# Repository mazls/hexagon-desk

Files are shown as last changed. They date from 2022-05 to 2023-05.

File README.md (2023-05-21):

<h1 align="center"> Hexagon Desk </h1>
<h3 align="center"> Epoxy Coffe Table </h3>

This work is licensed under a
[Creative Commons Attribution-NonCommercial-ShareAlike 4.0 International License][cc-by-nc-sa].

[][cc-by-nc-sa]

[cc-by-nc-sa]: http://creativecommons.org/licenses/by-nc-sa/4.0/
[cc-by-nc-sa-image]: https://licensebuttons.net/l/by-nc-sa/4.0/88x31.png
[cc-by-nc-sa-shield]: https://img.shields.io/badge/License-CC%20BY--NC--SA%204.0-lightgrey.svg
<p align="center"> 
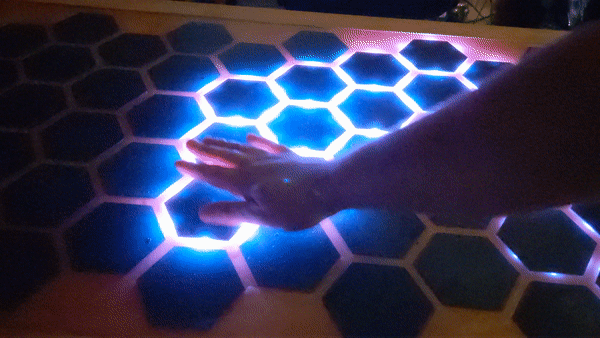
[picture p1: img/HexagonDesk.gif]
Hexagon Desk
  
</p>

<!-- TABLE OF CONTENTS -->
<h2 id="table-of-contents"> :book: Table of Contents</h2>

<details open="open">
  <summary>Table of Contents</summary>
  <ol>
    <li><a href="#about-the-project"> ➤ About The Project</a></li>
    <li><a href="#overview"> ➤ Overview</a></li>
    <li><a href="#project-files-description"> ➤ Project Files Description</a></li>
    <li><a href="#getting-started"> ➤ Getting Started</a></li>
    <li><a href="#PCB"> ➤ PCB: Main-PCB </a></li>
	<li><a href="#HexagonPCB"> ➤ PCB: HexagonPCB </a></li>
	<li><a href="#Links"> ➤ Useful Links: </a></li>
	<li><a href="#Sponsor"> ➤ Sponsor: </a></li>
  </ol>
</details>



<!-- ABOUT THE PROJECT -->
<h2 id="about-the-project"> :pencil: About The Project</h2>

<p align="justify"> 
  I saw a short TikTok with a led table that lights up when touched and immediately felt like building it myself. So i designed my own Main-PCB and little hexagonal PCBs for the light and touch. Unfortunately, there were a few setbacks due to the availability of some components. So I had to equip the main PCB with self soldered components. I also had to get the touch sensors externally and solder them on. If the whole thing with the chips calms down a bit I will tackle the whole thing again and simplify it.
</p>
<p align="center"> 
  HexagonDesk
</p>



<!-- OVERVIEW -->
<h2 id="overview"> :cloud: Overview</h2>

<p align="justify"> 
  This project still requires a lot of manual work. The main board still has to be assembled by yourself, as well as the touch sensors on the Hexagon boards.
Also a lot of wiring has to be done. The touch sensors are individually connected to the main board. The WS2812B on the hexagons are looped through per channel.

I have created a bom and instructions. however, these are still far from good. I am always working on improving these and also on the programme/boards.
I have opened the discussions area for questions, suggestions etc.
</p>
<p align="center"> 
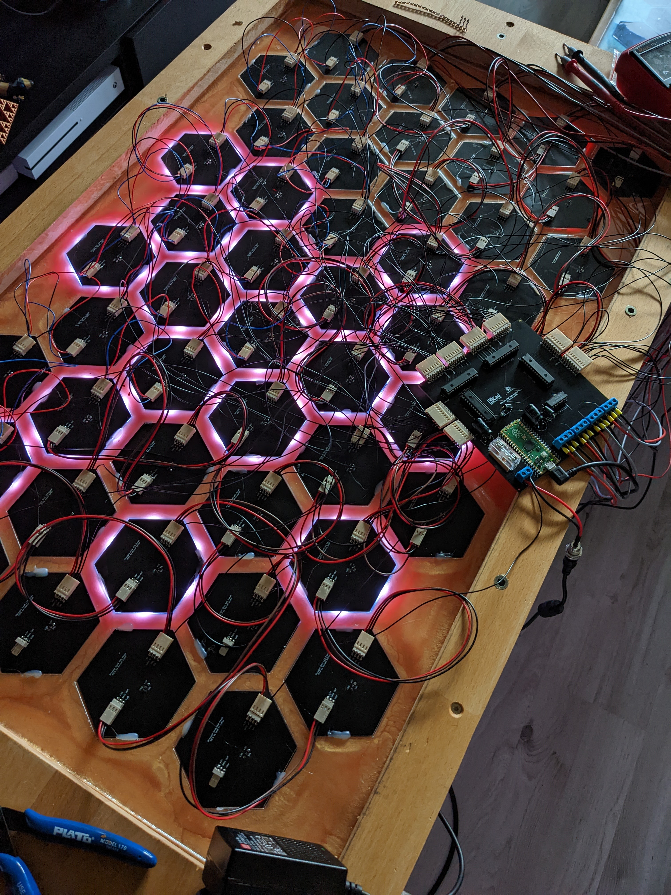
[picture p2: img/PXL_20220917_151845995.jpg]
HexagonWiring
  
</p>



<!-- PROJECT FILES DESCRIPTION -->
<h2 id="project-files-description"> :floppy_disk: Project Files Description</h2>

<ul>
  <li><b>Desk_PRG.ino</b> - Is the first version with an ESP32 as main controller</li>
  <li><b>Desk_PRG_RP2040.ino</b> - Is the current version with a RP2040 as controller.</li>
  <li><b>Adafruit_MCP23017.cpp/Adafruit_MCP23017.h</b> - Is for the MCP23017 I2C communication</li>
  <li><b>FastLED</b> - This is a modified Version of FastLED V3.4 to work with the RP2040</li>
</ul>



<!-- GETTING STARTED -->
<h2 id="getting-started"> :book: Getting Started</h2>
<p>Install the RP2040 Board: https://github.com/earlephilhower/arduino-pico </p>
<p>For ESP32 you have to install ESP32 Boards: https://randomnerdtutorials.com/installing-the-esp32-board-in-arduino-ide-windows-instructions/ </p>

<p>For RP2040 You have to clone the repo and copy the FastLED folder in your "...\Dokuments\Arduino\libraries\" folder to work with the RP2040</p>

<p>Now you should be able to compile the</p>
<pre><code>Desk_PRG_RP2040.ino</code></pre>

<p>In the header you should config your Setup</p>
<p>Just configure the amount of Hexagon PCBs you have connectet to channel 0-3</p>
<pre><code>#define Hexagons_channel_0  12</code></pre>
<pre><code>#define Hexagons_channel_1  12</code></pre>
<pre><code>#define Hexagons_channel_2  12</code></pre>
<pre><code>#define Hexagons_channel_3  14</code></pre>
<p>In this config i have connectet 12 Hexagon PCBs to channel 0, 12 Hexagon PCBs to channel 1, 12 Hexagon PCBs to channel 2 and 14 Hexagon PCBs to channel 3. The desk was build with 50 Hexagon PCBs. The maximum is 64, but this can be expanded with more MCP23017.
</p>



<!-- Main-PCB -->
<h2 id="Main-PCB"> :small_orange_diamond: Main-PCB: What is the Main-PCB</h2>

<p> The Main-PCB contains 4x MCP23017, 2x 1500uF Capacitor, 1x Fuse holder, 1x SN74HC125N and one ESP32 Dev Kit C / Raspberry Pi Pico</p>
<p>The MCP23017 are communicating over I2C, every MCP23017 has 16 Inputs/Outputs.</p>
<p>The SN74HC125N is to shift the data channel from 3.3V to 5V so the leds don't glitch.</p>



<!-- HexagonPCB -->
<h2 id="HexagonPCB"> :small_orange_diamond: HexagonPCB: The LED and Touch PCBs</h2>

<p>I have designed this PCB to integrate the LEDs and the Touch Sensor.</p>
<p>The PCB has a "Data IN" and "Data OUT" so it is possible to connect multiple PCBs to act as a WS2812B Strip</p>
<p>Every PCB has a "Signal" Pin which connects the signal output from the TTP223 PCB to the Main-PCB</p>
<p>The Input Voltage is 5V for the PCB</p>
<p>I have scraped some varnish from the touch surface of the TTP223 sensors and soldered a cable there, which then functions as a touch sensor.</p>

<p align="center"> 
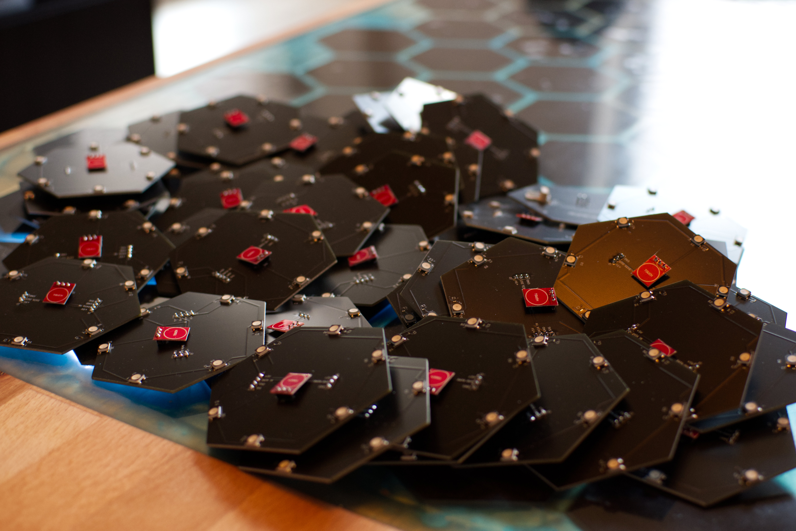
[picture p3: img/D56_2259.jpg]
HexagonPCB
  
</p>



<!-- Links -->
<h2 id="Links"> :scroll: Some useful Links: </h2>

<p>BOM</p>
[Tisch_BOM.xlsx](https://github.com/mazls/hexagon-desk/blob/main/BOM/Tisch_BOM.xlsx)
</p>

<p>Schematic Wiring</p>
[Wiring.pdf](https://github.com/mazls/hexagon-desk/files/8800328/Wiring.pdf)
</p>
<p>Desk Cutout for 50 Hexagons</p>
[Hex_Desk_Ausschnitt.pdf](https://github.com/mazls/hexagon-desk/blob/main/Woodwork/Hex_Desk_Ausschnitt.pdf)
</p>
<p>Desk Legs</p>
[Table_legs.pdf](https://github.com/mazls/hexagon-desk/blob/main/Woodwork/Table_legs.pdf)
</p>

<p>Print files can be found here:</p>
https://www.printables.com/model/200964-hexagon-led-coffee-table
<p align="center"> 
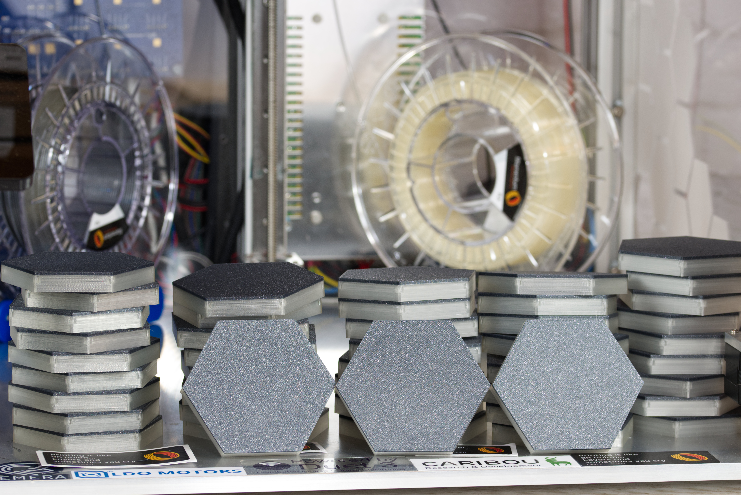
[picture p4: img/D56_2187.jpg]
HexagonPrint
  
</p>

</p>
<p>Dev Kit link:</p>
https://www.az-delivery.de/en/products/esp32-developmentboard
</p>
<p>Videos</p>
https://youtu.be/I4rWym8PK4s

https://www.youtube.com/watch?v=-OrUfqWGYhM&feature=emb_title



<!-- Sponsor -->
<h2 id="Sponsor"> ➤ Sponsor: </h2>
PCBway kindly sponsored a batch of PCBs which you can see pictures of inside the _img folder.
The pcbs came in an absolutely outstanding quality and also very fast!
<p>Ordering at PCBWay is simple:</p>
Upload the files from the desired folder
After submitting your file, a PCBWay engineer will spend a few minutes reviewing your file to make sure everything goes smoothly for production. For high-priority work, it's always good to see how things are progressing. You have the opportunity to check the production status of each step. For assembled PCB, PCBWay will also send you sample photos for preview and confirmation.

<p align="center"> 
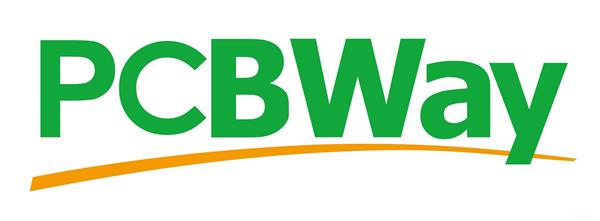
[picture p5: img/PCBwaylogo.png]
  
</p>

http://pcbway.com

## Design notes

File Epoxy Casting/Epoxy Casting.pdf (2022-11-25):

Epoxy Casting:

1. Pour in one layer about 2mm thick with clear epoxy
2. Let it harden (one day)
3. Pour in a second layer about 1-2mm but also brush the hexagons with epoxy and place them inside the table
4. Let all harden
5. Pour the color layer to max hexagon height

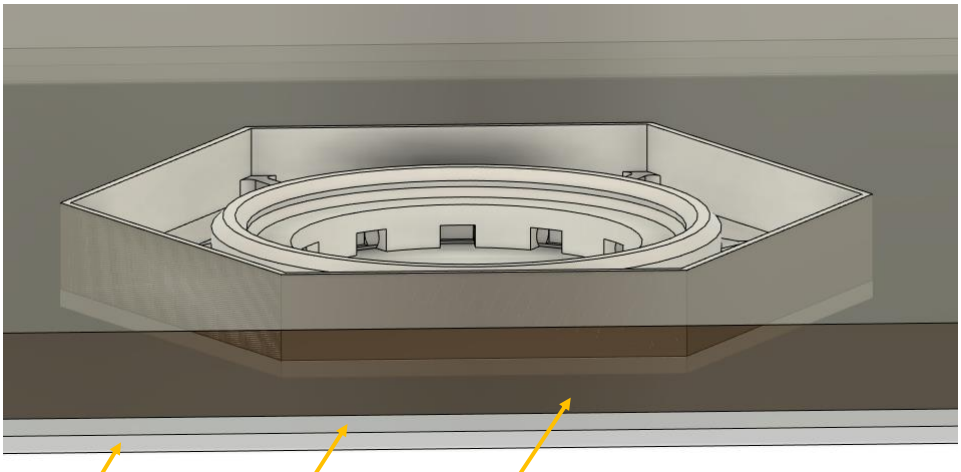
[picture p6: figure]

1. Clear Layer | 2. Clear Layer with Hexagons

3.Color Layer

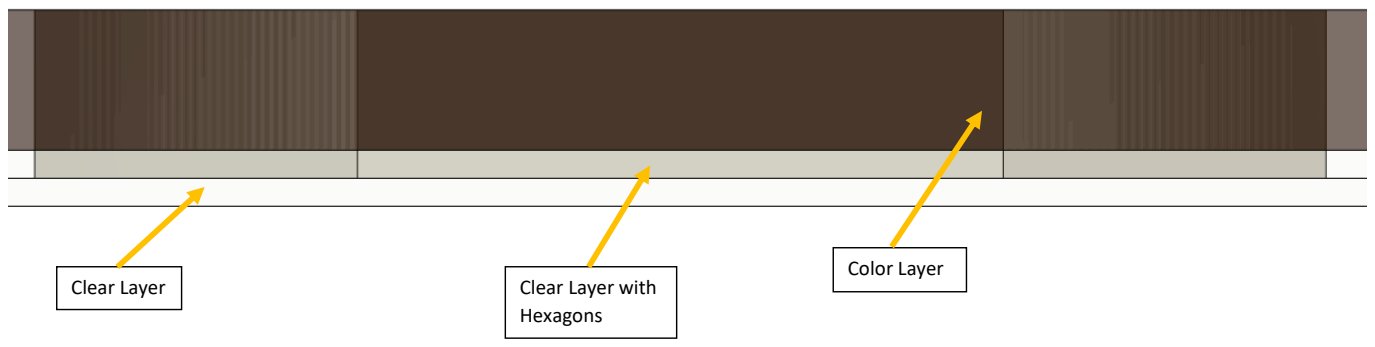
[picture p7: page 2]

Color Layer
Clear Layer with
Hexagons

Clear Layer

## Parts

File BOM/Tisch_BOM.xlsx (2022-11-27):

Name | Anzahl | Preis | Gesamt | Bild | Link
Hexagon PCB | 50 | 4.20 € | 210.00 € |  | PCBWay
Main PCB | 1 | 6.97 € | 6.97 € |  | PCBWay
2 Pol Schraubklemme | 1 | 0.40 € | 0.40 € |  | CTB0102-2: Lötbare Schraubklemme - 2-pol, RM 5 mm, 90° bei reichelt elektronik (https://www.reichelt.de/loetbare-schraubklemme-2-pol-rm-5-mm-90--ctb0102-2-p292680.html?trstct=pos_1&nbc=1)
3 Pol Schraubklemme | 4 | 0.40 € | 1.60 € |  | CTB0102-3: Lötbare Schraubklemme - 3-pol, RM 5 mm, 90° bei reichelt elektronik (https://www.reichelt.de/loetbare-schraubklemme-3-pol-rm-5-mm-90--ctb0102-3-p292681.html?trstct=vrt_pdn&nbc=1)
Sicherungshalter | 1 | 0.20 € | 0.20 € |  | HALJIA 10 x Leiterplatten-Sicherungshalter mit Abdeckung für Sicherungen mit 5 x 20 mm, 250 V, 6 A: Amazon.de: Baumarkt (https://www.amazon.de/gp/product/B07BFMXHN8/ref=ppx_yo_dt_b_search_asin_title?ie=UTF8&psc=1)
Sicherung | 1 | 0.20 € | 0.20 € |  | BOJACK 15 Values 150pcs Schnellschlag Glassicherungen Sortiment Set 5x20mm Sicherung 250V Sicherungen 0,1 0,2 0,25 0,5 1 1,5 2 3 4 5 8 10 12 15 20A Verpackung in einer durchsichtigen Kunststoffbox : Amazon.de: Baumarkt (https://www.amazon.de/gp/product/B07TF68QZC/ref=ppx_yo_dt_b_search_asin_title?ie=UTF8&psc=1)
Kondensator 1500uF | 1 | 1.40 € | 1.40 € |  | Aerzetix: 5x LOW ESR Kondensator chemischen 1500μF ± 20% 16V THT 105 ° C 5000h Radial Ø12.5x20mm 0.05Ω 1400mA C14706: Amazon.de: Gewerbe, Industrie & Wissenschaft (https://www.amazon.de/Aerzetix-Kondensator-chemischen-1500%CE%BCF-%C3%9812-5x20mm/dp/B01N15CYYA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)
Leimholzplatte (Buche, Qualität: A/B, 1.000x600 x 18 mm) | 3 | 34.50 € | 103.50 € |  | Exclusivholz Leimholzplatte (Buche, Qualität: A/B, 1.000 x 600 x 18 mm) | BAUHAUS (https://www.bauhaus.info/leimholzplatten/exclusivholz-leimholzplatte/p/14035174)
MCP23017 | 4 | 1.85 € | 7.40 € |  | MCP 23017-E - SP: I - O-Erweiterung, 16bit, 1,8 - 5V, Seriell, I2C, DIP-28 bei reichelt elektronik (https://www.reichelt.de/i-o-erweiterung-16bit-1-8-5v-seriell-i2c-dip-28-mcp-23017-e-sp-p140074.html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)
SN74HC125N | 1 | 0.34 € | 0.34 € |  | 74HC 125: BUS Puffer, 3-State, 2 ... 6 V, DIL-14 bei reichelt elektronik (https://www.reichelt.de/bus-puffer-3-state-2--6-v-dil-14-74hc-125-p3132.html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)
DC Hohlstecker 5.5x2.1mm | 1 | 1.30 € | 1.30 € |  | RUNCCI-YUN DC Mount Adapter Set, 6X DC Hohlstecker（Mit Kabel） 6 X DC Power Jack Socket 5,5 X 2,1 mm DC Stecker Buchse Adapter für Audio/Video/Handy/Überwachungskameras: Amazon.de: Elektronik & Foto (https://www.amazon.de/gp/product/B089DXQDS9/ref=ppx_yo_dt_b_search_asin_title?ie=UTF8&psc=1)
5v Netzteil | 1 | 18.70 € | 18.70 € |  | GS15E-1P1J: Steckernetzteil, 12 W, 5 V, 2,4 A, stabilisiert bei reichelt elektronik (https://www.reichelt.de/steckernetzteil-12-w-5-v-2-4-a-stabilisiert-gs15e-1p1j-p161604.html?trstct=pos_0&nbc=1)
TTP223 Touch sensor | 61 | 0.50 € | 30.50 € |  | TTP223 Touch Schlüssel Schalter Modul Berühren Taste Self Locking/Keine Kapazitiven Schalter Einzel Kanal Wiederaufbau|Integrierte Schaltkreise| - AliExpress (https://de.aliexpress.com/item/33010351631.html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)
Epoxid Harz 4.5kg | 1 | 59.99 € | 59.99 € |  | EpoxyPlast 3D B50 Deep Pour Resin - Ultra Diamond Clear Anti-UV - E... (kandydip.de) (https://kandydip.de/ecom/prestashop/epoxidharz-dipon/3993-epoxyplast-3d-b50-deep-pour-resin-ultra-diamond-clear-anti-uv-epoxidharz-i-epoxy-resin-diponr.html)
Formtrennband | 1 | 6.05 € | 6.05 € |  | Formentrennband für Epoxidharze - Trennmittel I Release Agents (kandydip.de) (https://kandydip.de/ecom/prestashop/trennmittel-i-release-agents/4010-formentrennband-fur-epoxidharze-trennmittel-i-release-agents-diponr-4063636027441.html)
Metallic Pulver | 1 | 8.99 € | 8.99 € |  | Red Firestorm Colorshift Pearl Pigment - ColorShifts (kandydip.de) (https://kandydip.de/ecom/prestashop/dipon-colorshift-pearls/1590-red-firestorm-colorshift-pearl-pigment-colorshifts-diponr-4063636005364.html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)
Holzeinsätze M6 - 10mm | 20 | 0.30 € | 6.00 € |  | FTVOGUE 20 stücke Innensechskant Antriebskopfschraube Kohlenstoffstahl Insert Muttern Gewinde für Holz Möbel (M6*10mm) : Amazon.de: Baumarkt (https://www.amazon.de/gp/product/B07PYP344Y/ref=ppx_yo_dt_b_search_asin_title?ie=UTF8&psc=1)
M6x 16 Schrauben | 50 | 0.17 € | 8.35 € |  | M6 ISO 7380-2 A2 V2A Edelstahl Linsenkopfschrauben Innensechskant Flansch M6x | eBay (https://www.ebay.de/itm/162277039480)
PETG Schwarz | 1 | 29.99 € | 29.99 €
PETG Transparent | 1 | 29.99 € | 29.99 €
Hartöl | 1 | 19.95 € | 19.95 € |  | CLOU Hartöl: Zur Renovierung und Pflege von stark beanspruchtem Massivholz, z.B. Treppen, Möbel und Parkett, farblos, 0,75 L : Amazon.de: Baumarkt (https://www.amazon.de/CLOU-304843-Clou-Hart%C3%B6l-farblos/dp/B004GTYPFC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)
IC Buchsen Set | 1 | 8.99 € | 8.99 € |  | DollaTek 66-teilige Dip-IC-Buchsen Adapter Lötbuchsen-Kit 6/8/14/16/18/20/24/28 Stifte : Amazon.de: Gewerbe, Industrie & Wissenschaft (https://www.amazon.de/gp/product/B08HQW9PS8/ref=ppx_yo_dt_b_search_asin_title?ie=UTF8&psc=1)
Kupplungs-Leergehäuse, Crimptechnik, 3-polig | 100 | 0.02 € | 2.00 € |  | PSK 254 - 3W: Kupplungs-Leergehäuse, Crimptechnik, 3-polig bei reichelt elektronik (https://www.reichelt.de/kupplungs-leergehaeuse-crimptechnik-3-polig-psk-254-3w-p14858.html?trstct=pos_0&nbc=1)
PSK 254/4W Kupplungs-Leergehäuse, Crimptechnik, 4-polig | 100 | 0.02 € | 2.00 € |  | PSK 254 - 4W: Kupplungs-Leergehäuse, Crimptechnik, 4-polig bei reichelt elektronik (https://www.reichelt.de/kupplungs-leergehaeuse-crimptechnik-4-polig-psk-254-4w-p694.html?trstct=pos_0&nbc=1)
PSK 254/8W Kupplungs-Leergehäuse, Crimptechnik, 8-polig | 4 | 0.04 € | 0.16 € |  | PSK 254 - 8W: Kupplungs-Leergehäuse, Crimptechnik, 8-polig bei reichelt elektronik (https://www.reichelt.de/kupplungs-leergehaeuse-crimptechnik-8-polig-psk-254-8w-p14860.html?trstct=pos_0&nbc=1)
CRIMPZANGE PSK | 1 | 20.30 € | 20.30 € |  | CRIMPZANGE PSK: Crimpzange, PSK-Kontakte bei reichelt elektronik (https://www.reichelt.de/crimpzange-psk-kontakte-crimpzange-psk-p6844.html?&trstct=pos_1&nbc=1)
PSK-KONTAKTE 20x | 50 | 0.24 € | 12.00 € |  | PSK-KONTAKTE: Crimpkontakte für psk 254 - ..., 20 Stück bei reichelt elektronik (https://www.reichelt.de/crimpkontakte-fuer-psk-254--20-stueck-psk-kontakte-p14861.html?trstct=pos_0&nbc=1)
PSS 254/3W Printstecker | 100 | 0.09 € | 9.00 € |  | PSS 254 - 3W: Printstecker, Einzelstecker, gewinkelt, 3-polig bei reichelt elektronik (https://www.reichelt.de/printstecker-einzelstecker-gewinkelt-3-polig-pss-254-3w-p14910.html?trstct=pos_0&nbc=1)
PSS 254/4W | 100 | 0.13 € | 13.00 € |  | PSS 254 - 4W: Printstecker, Einzelstecker, gewinkelt, 4-polig bei reichelt elektronik (https://www.reichelt.de/printstecker-einzelstecker-gewinkelt-4-polig-pss-254-4w-p137974.html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)
PSS 254/8W | 4 | 0.11 € | 0.44 € |  | PSS 254 - 8W: Printstecker, Einzelstecker, gewinkelt, 8-polig bei reichelt elektronik (https://www.reichelt.de/printstecker-einzelstecker-gewinkelt-8-polig-pss-254-8w-p14914.html?trstct=pos_0&nbc=1)
Pi Pico, RP2040 | 1 | 4.00 € | 4.00 € |  | RASP PI PICO: Raspberry Pi Pico, RP2040, Cortex-M0+, microUSB bei reichelt elektronik (https://www.reichelt.de/raspberry-pi-pico-rp2040-cortex-m0-microusb-rasp-pi-pico-p295706.html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)
LITZE BL | 5 | 0.95 € | 4.75 € |  | LITZE BL: Kupferlitze isoliert, 10 m, 1 x 0,14 mm², blau bei reichelt elektronik (https://www.reichelt.de/kupferlitze-isoliert-10-m-1-x-0-14-mm-blau-litze-bl-p10292.html?trstct=pos_0&nbc=1)
LITZE SW | 5 | 0.95 € | 4.75 € |  | LITZE SW: Kupferlitze isoliert, 10 m, 1 x 0,14 mm², schwarz bei reichelt elektronik (https://www.reichelt.de/kupferlitze-isoliert-10-m-1-x-0-14-mm-schwarz-litze-sw-p10298.html?search=LITZE+sw)
LITZE RT | 5 | 0.95 € | 4.75 € |  | LITZE RT: Kupferlitze isoliert, 10 m, 1 x 0,14 mm², rot bei reichelt elektronik (https://www.reichelt.de/kupferlitze-isoliert-10-m-1-x-0-14-mm-rot-litze-rt-p10297.html?trstct=pos_0&nbc=1)
 |  |  | 637.96 €

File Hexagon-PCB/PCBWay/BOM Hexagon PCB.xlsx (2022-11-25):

 |  |  | xxxx xxxx xxxxx xxPCS BOM (Sample Bill of Materials)
Item # | *Designator | *Qty | Manufacturer | *Mfg Part # | Description / Value | *Package/Footprint | Type | Your Instructions / Notes
1 | D1, D2, D3, D4, D5, D6 | 6 | Worldsemi | WS2812B-B | RGB 5050(mm) Light Emitting Diodes (LED) ROHS | 5050(mm) | SMD
2 | C1, C2, C3, C4, C5, C6 | 6 | Samsung Electro-Mechanics | CL05B104KO5NNNC | 16V 100nF X7R ±10% 0402 Multilayer Ceramic Capacitors MLCC - SMD/SMT ROHS | 0402 | SMD
Need a quick and accurante quote? Need an efficient production? Please read SMT Ordering Necessary Files & Info in 1 minute. Thank you very much! (https://www.pcbway.com/smt_ordering_guide.html)
Click for Instructions on How to Create a BOM (https://www.pcbway.com/blog/PCB_Assembly/How_to_Build_a_BOM__Bill_Of_Materials_.html)

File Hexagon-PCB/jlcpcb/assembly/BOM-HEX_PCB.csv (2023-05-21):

Comment | Designator | Footprint | LCSC
0.1uF | C1 | C_0201_0603Metric
WS2812B | D3 | LED_WS2812B_PLCC4_5.0x5.0mm_P3.2mm
0.1uF | C4 | C_0201_0603Metric
Conn_01x03_Male | J3 | PinHeader_1x03_P2.54mm_Vertical
WS2812B | D4 | LED_WS2812B_PLCC4_5.0x5.0mm_P3.2mm
0.1uF | C2 | C_0201_0603Metric
Conn_01x04_Male | J1 | PinHeader_1x04_P2.54mm_Vertical
WS2812B | D5 | LED_WS2812B_PLCC4_5.0x5.0mm_P3.2mm
0.1uF | C5 | C_0201_0603Metric
WS2812B | D6 | LED_WS2812B_PLCC4_5.0x5.0mm_P3.2mm
0.1uF | C3 | C_0201_0603Metric
Conn_01x03_Male | J2 | PinHeader_1x03_P2.54mm_Vertical
WS2812B | D1 | LED_WS2812B_PLCC4_5.0x5.0mm_P3.2mm
WS2812B | D2 | LED_WS2812B_PLCC4_5.0x5.0mm_P3.2mm
0.1uF | C6 | C_0201_0603Metric

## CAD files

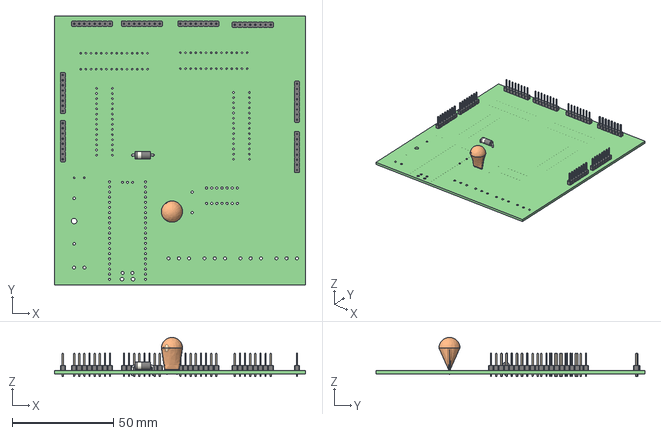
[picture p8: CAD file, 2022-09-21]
Desk_PRG/Desk_PRG_RP2040/Hexagon_Desk_RP2040.step
124.3 x 133.1 x 19.4 mm
Hexagon_Desk_RP2040 PCB

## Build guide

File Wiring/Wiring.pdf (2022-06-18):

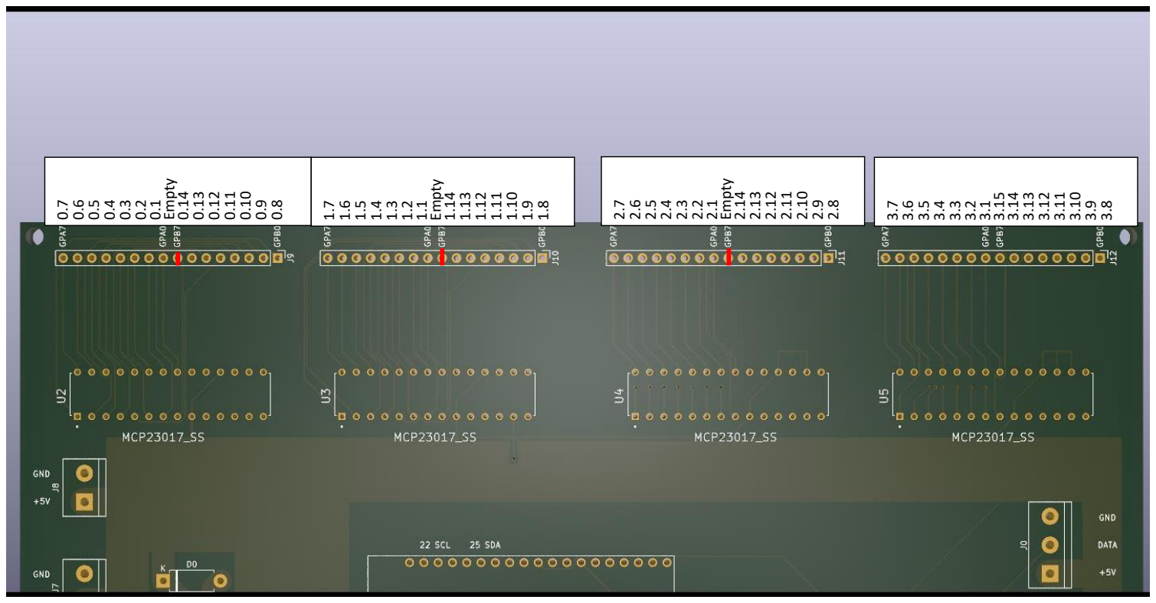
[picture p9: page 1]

0.7

0.6

0.5

0.4

0.3

0.2

0.1

Empty
0.14

0.13

0.12

0.11

0.10
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
Empty
1.14

1.13

1.12

1.11

1.10
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
Empty
2.14

2.13

2.12

2.11

2.10
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
3.15

3.14

3.13

3.12

3.11

3.10
3.9

3.8

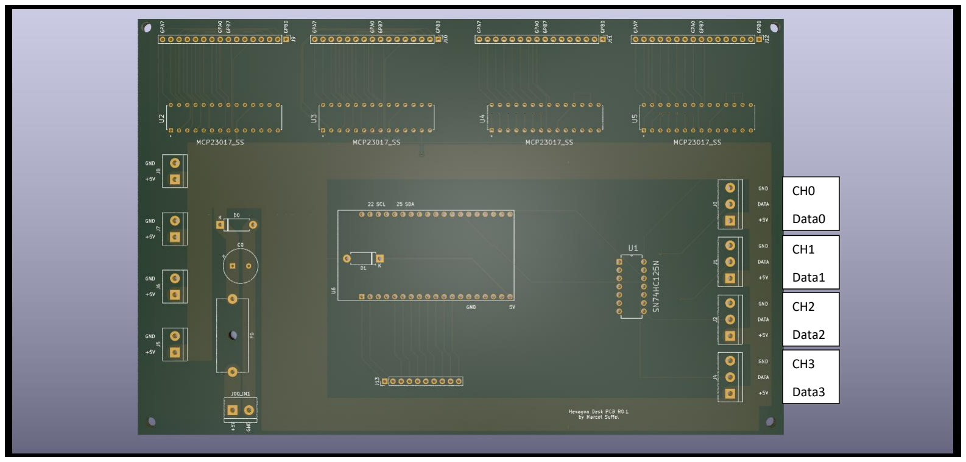
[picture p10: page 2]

CH0

Data0

CH1

Data1

CH2

Data2

CH3

Data3

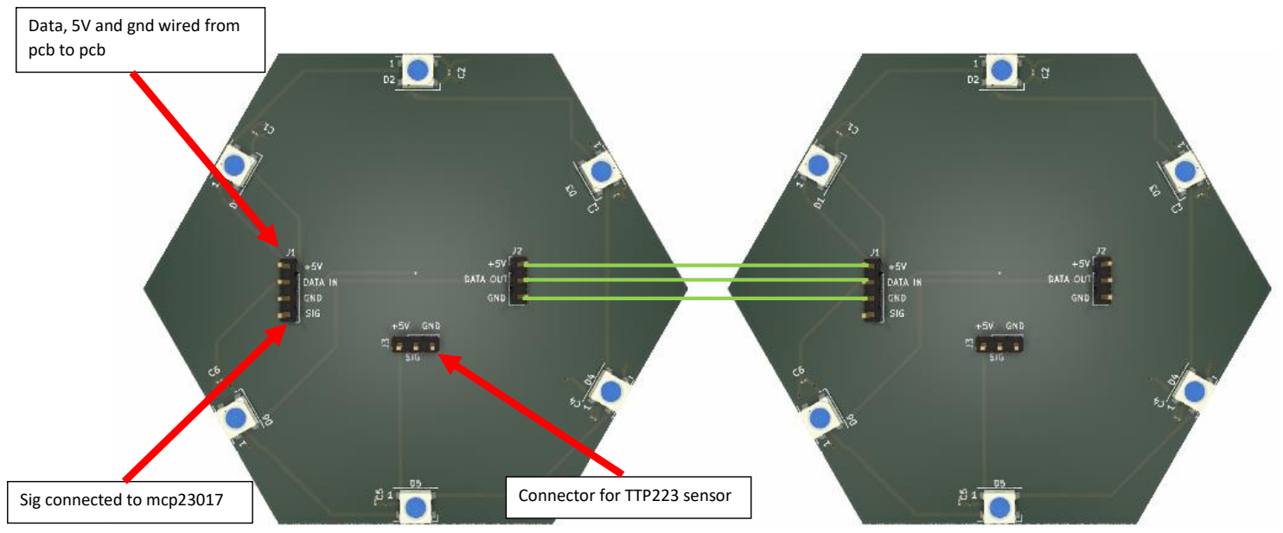
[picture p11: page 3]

Sig connected to mcp23017

Data, 5V and gnd wired from pcb to pcb

Connector for TTP223 sensor

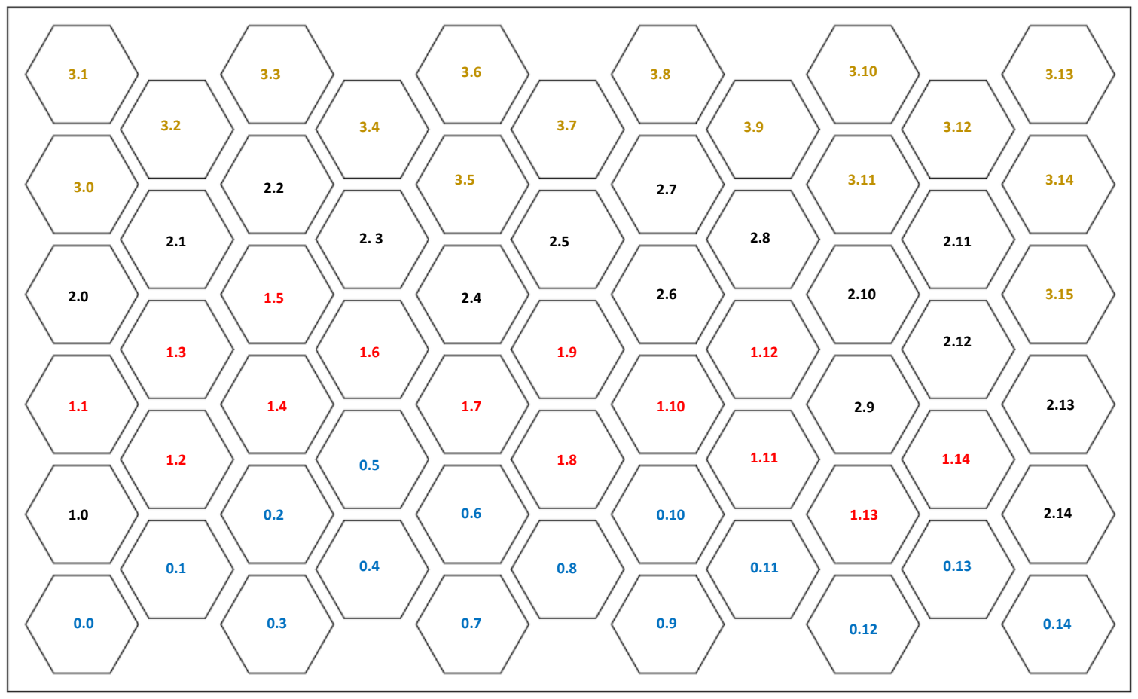
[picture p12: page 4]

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
0.10

0.9
0.12

0.11 0.13

0.14

1.0

1.2

1.1 1.4

1.3 1.6

1.5

1.7

1.8

1.9

1.10

1.11

1.12

1.13

1.14

2.0

2.1

2.2

2. 3

2.4

2.5

2.7

2.6

2.8

2.9

2.10

2.13

2.11

2.12

2.14

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
3.11

3.10

3.12

3.13

3.14

3.15

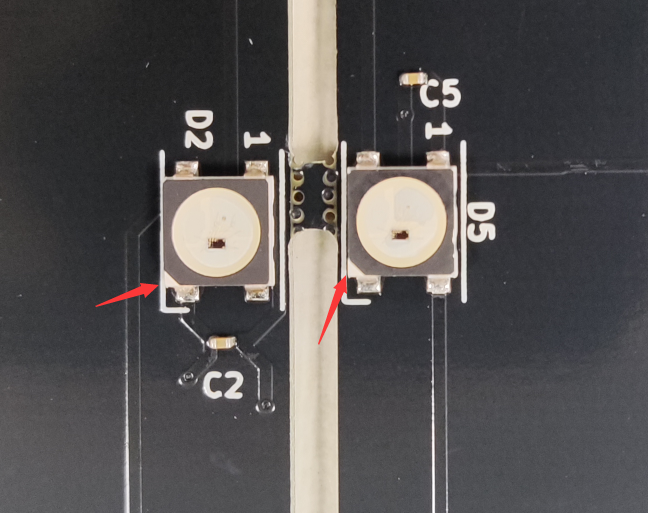
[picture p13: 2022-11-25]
Hexagon-PCB/PCBWay/ReferencePicture for Manufacturing/point to cathode.png

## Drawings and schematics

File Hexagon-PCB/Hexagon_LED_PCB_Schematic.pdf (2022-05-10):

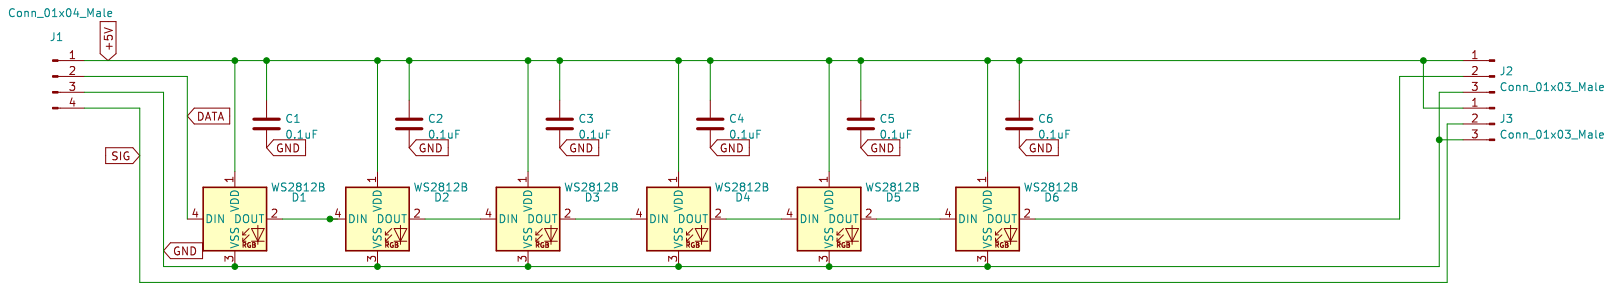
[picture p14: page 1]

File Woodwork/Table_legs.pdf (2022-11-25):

18

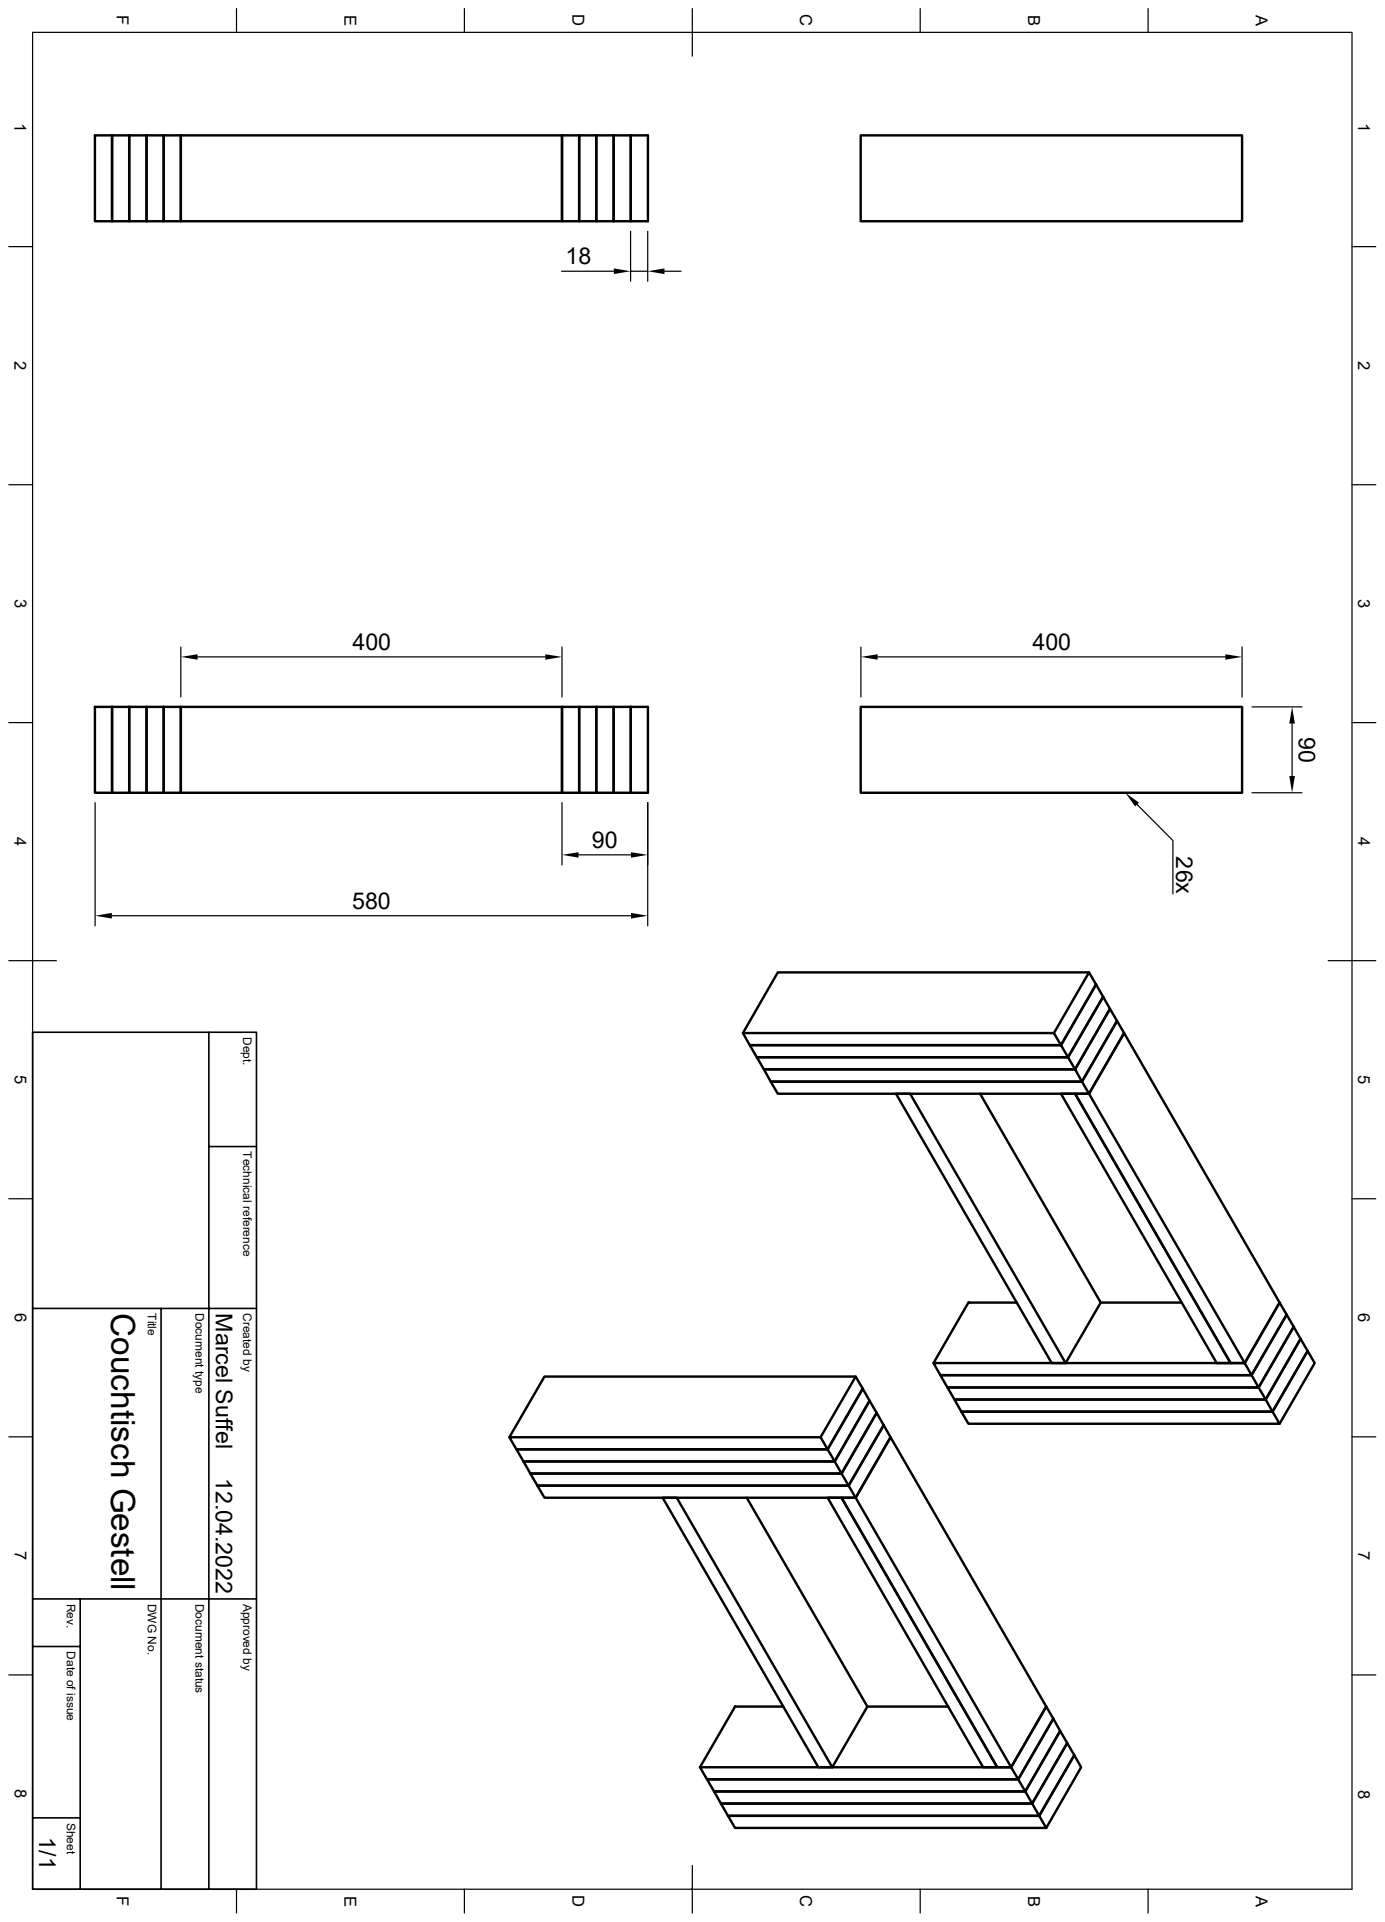
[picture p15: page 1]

1 A 2 3 4 5 6 7 8 1 2 3 4 5 6 7 8 FEDCB FEDCBA Dept. Technical reference Created by Approved by Title DWG No. Document type Document status Rev. Date of issue Sheet 12.04.2022 1/1 Couchtisch Gestell Marcel Suffel

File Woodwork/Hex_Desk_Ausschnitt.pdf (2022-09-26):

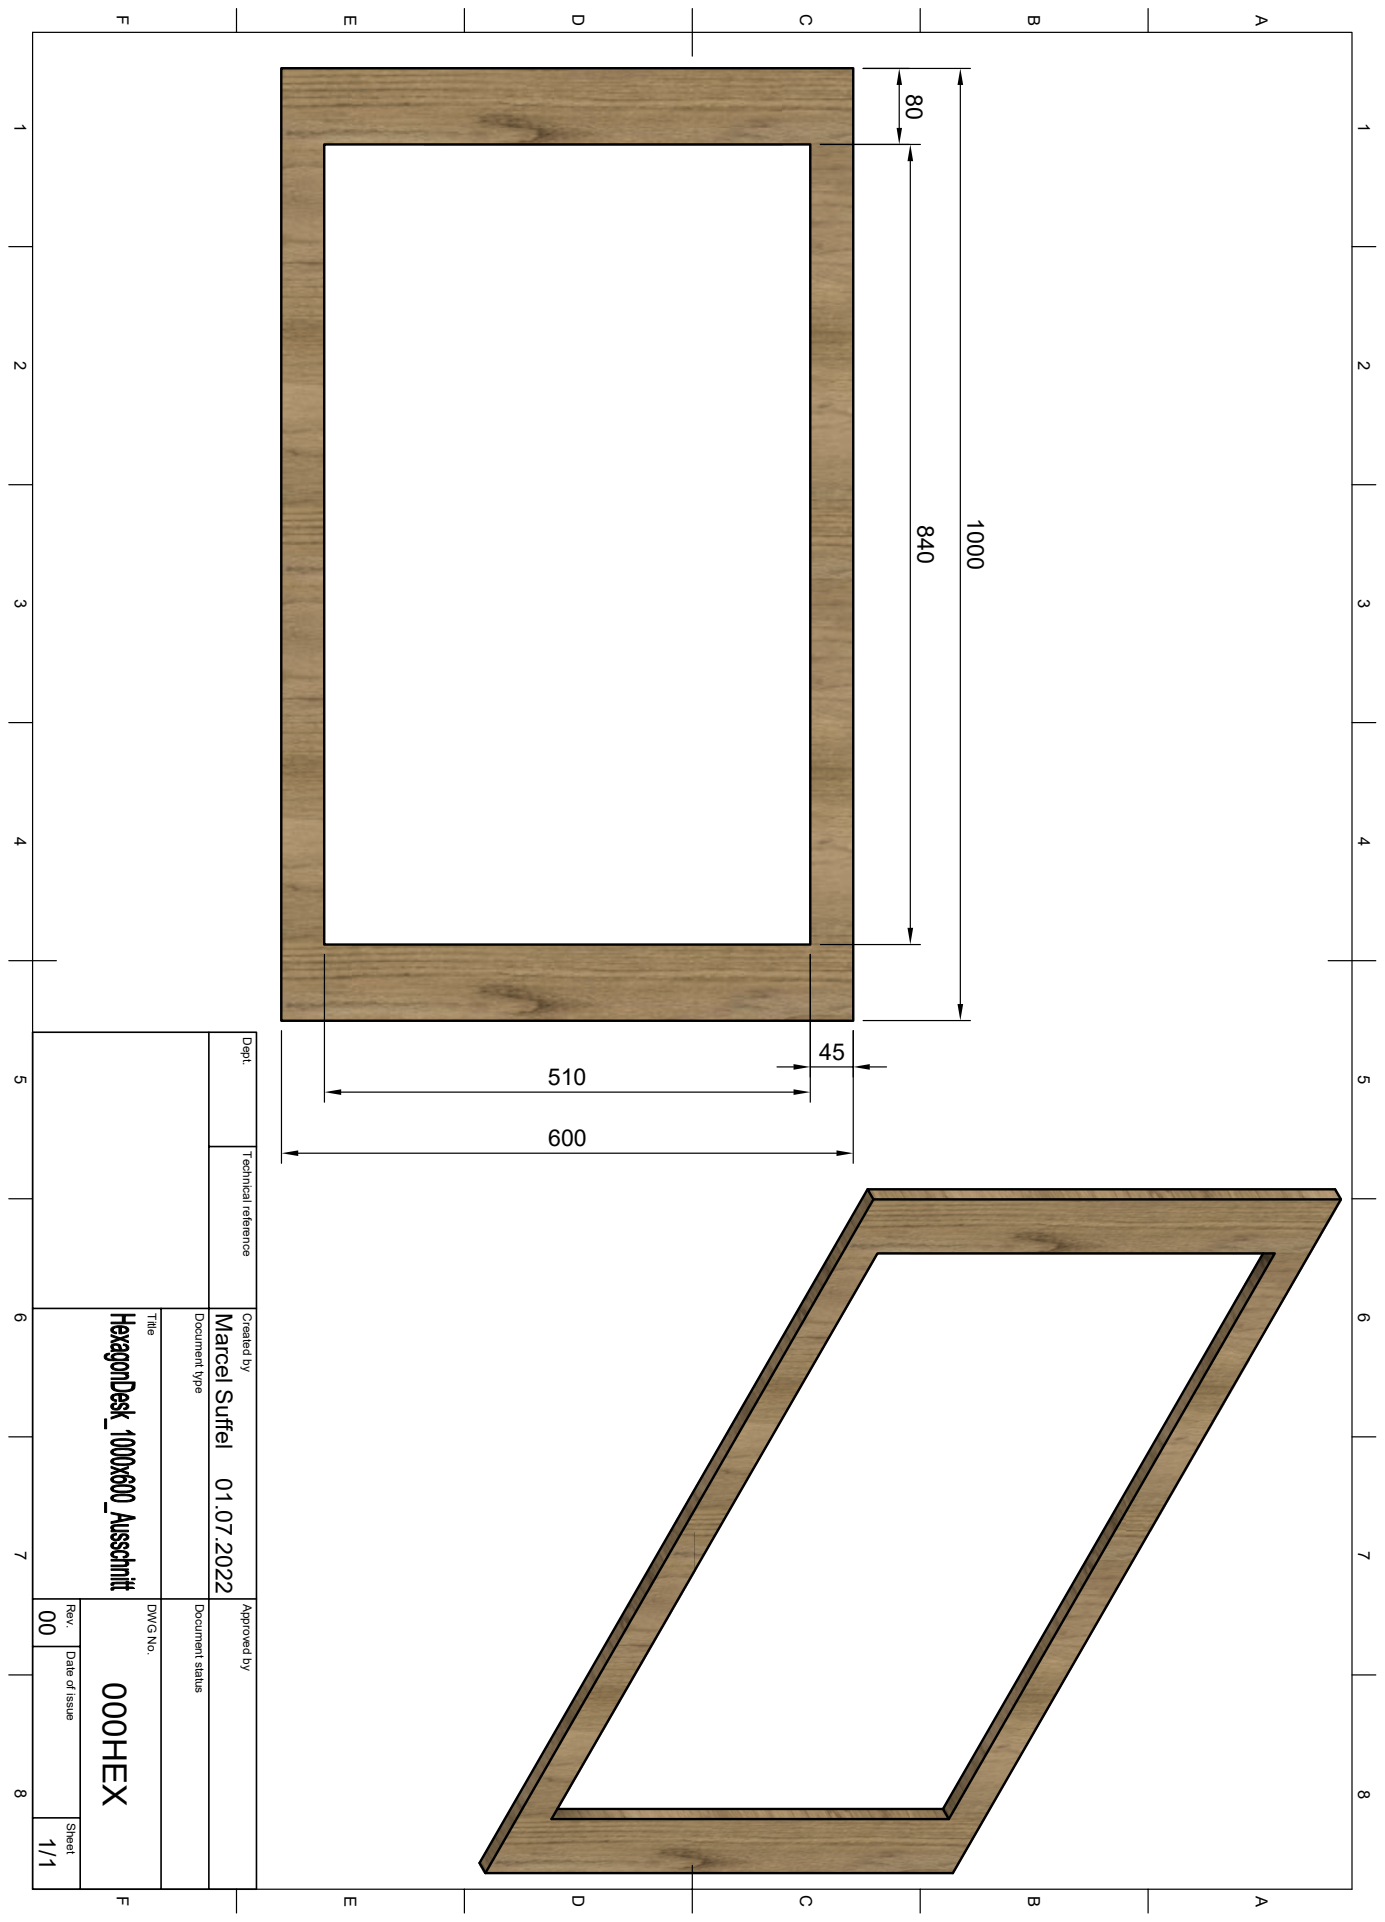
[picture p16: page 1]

1 A 2 3 4 5 6 7 8 1 2 3 4 5 6 7 8 FEDCB FEDCBA Dept. Technical reference Created by Approved by Title DWG No. Document type Document status 00 Rev. Date of issue Sheet 01.07.2022 1/1 000HEX Marcel Suffel 80

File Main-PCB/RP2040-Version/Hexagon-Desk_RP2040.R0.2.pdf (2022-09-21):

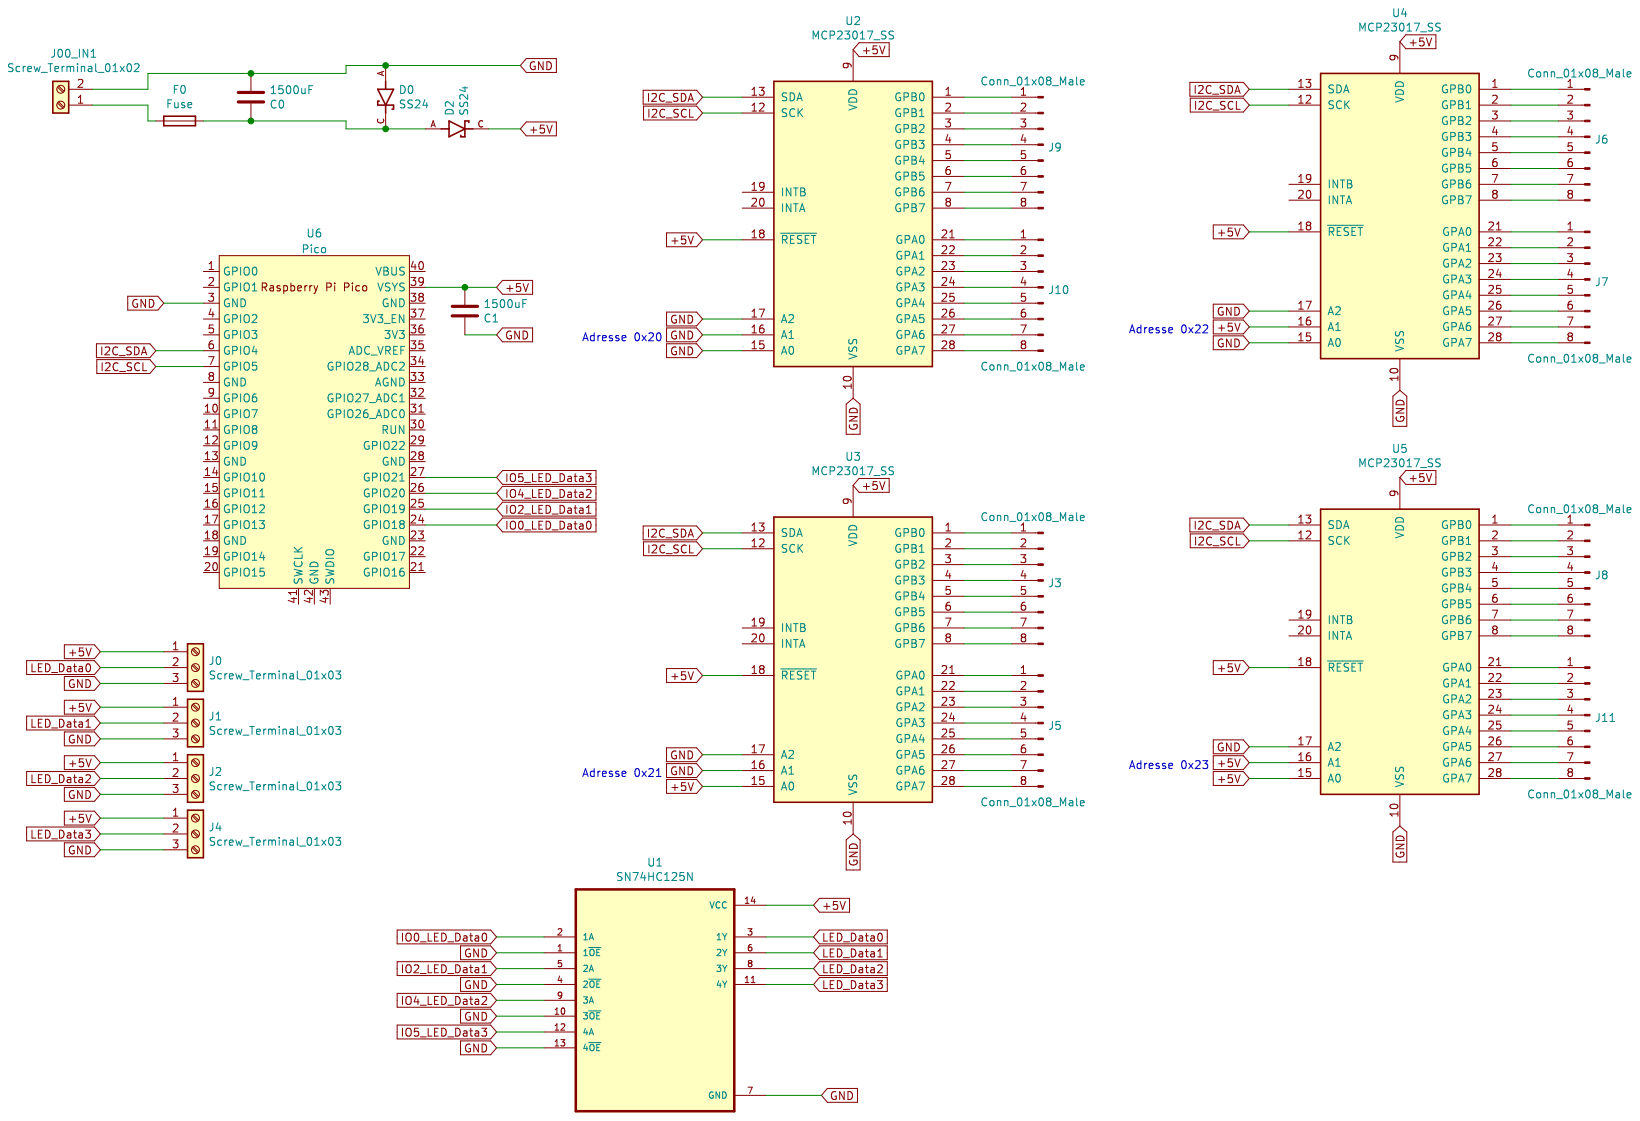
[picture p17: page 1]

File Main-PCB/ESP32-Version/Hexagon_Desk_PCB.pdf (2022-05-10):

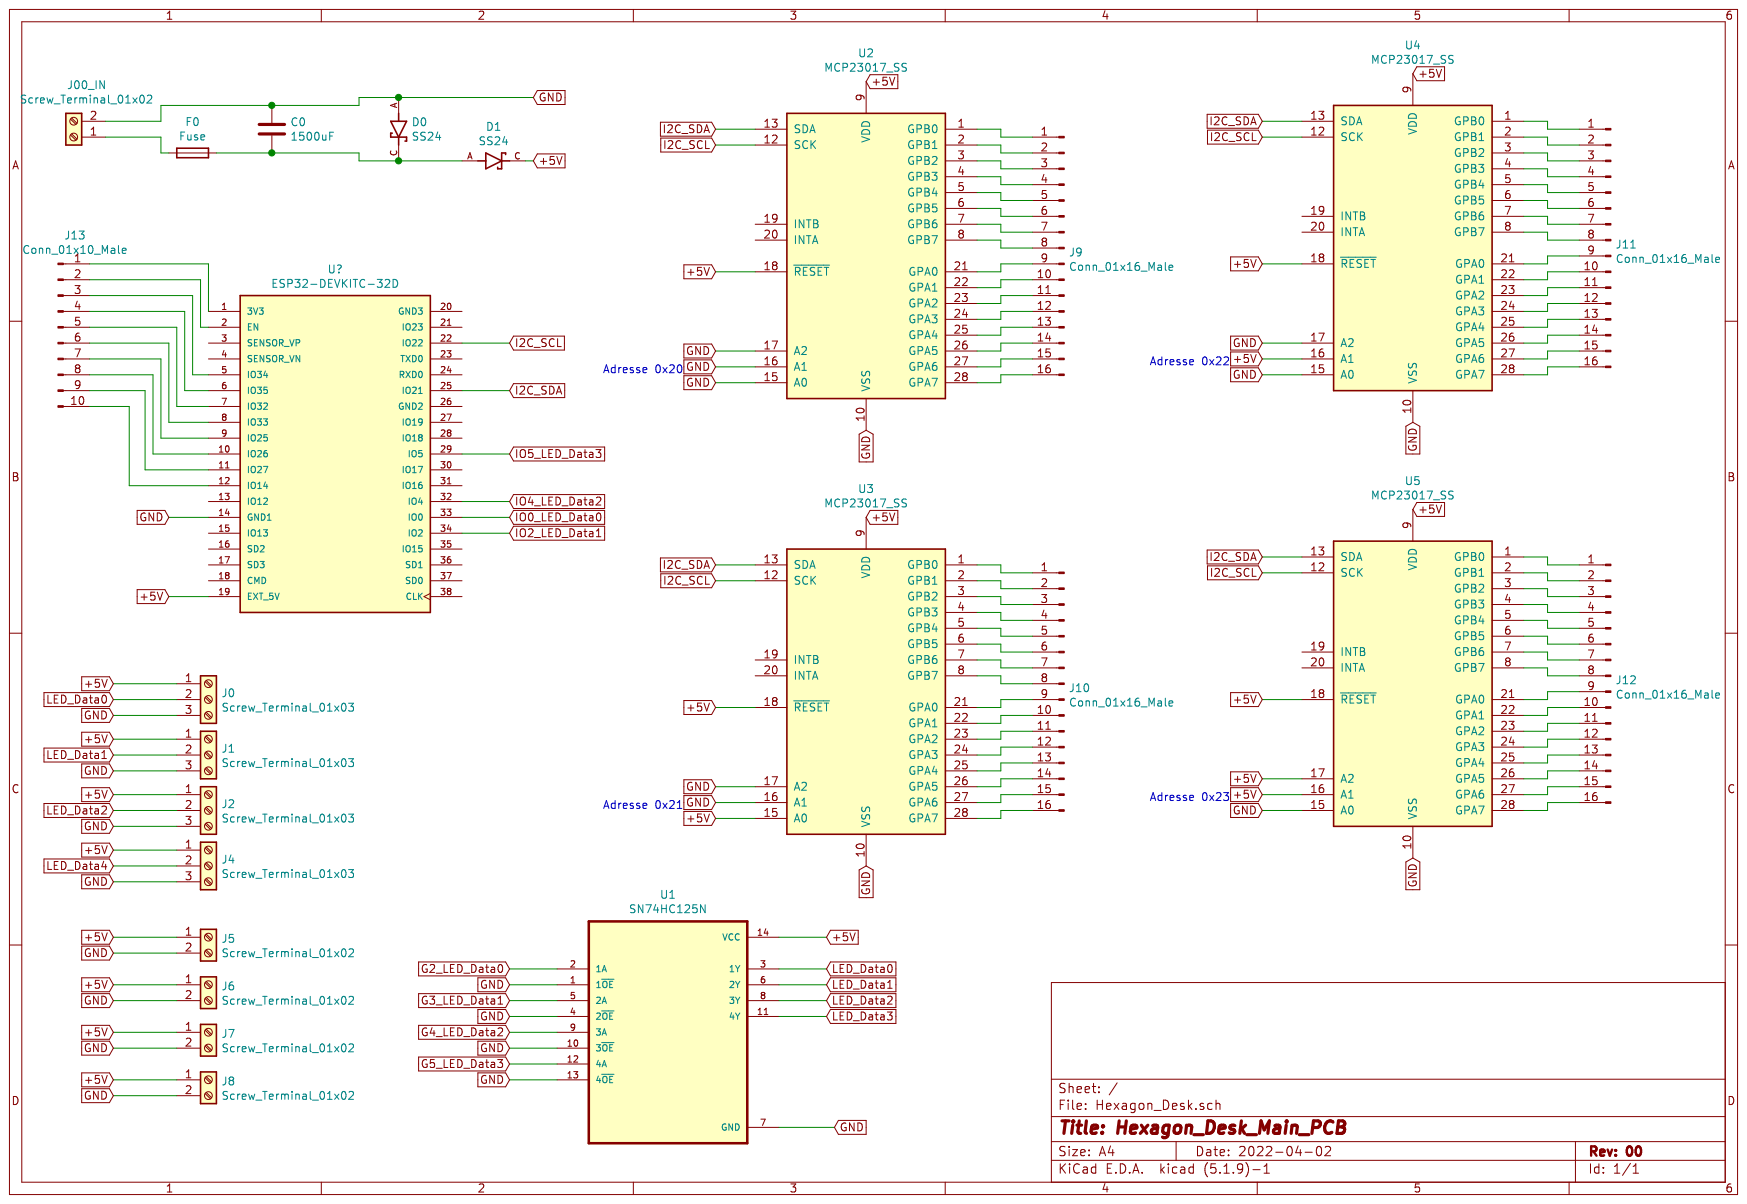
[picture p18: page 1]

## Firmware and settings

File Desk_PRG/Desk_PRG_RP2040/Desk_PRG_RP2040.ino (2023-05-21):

//+--------------------------------------------------------------------------
//
// mazls - (c) 2022 Marcel Suffel.  All Rights Reserved.
//
// File: Hexagon Desk Main Prg                 
//
// Description: Programm for Raspberry Pico RP2040; reads inputs from MCP23017 puts in array
//              4 LED channels to one array; Inputs TTP223 touch sensors
//              Hexagonal led pcbs, with 6 WS2812B leds and pins for TTP223 Sensors
//              
//   
//
// History:     May-14-2022     mazls      Created
//              Sep-05-2022     mazls      RP2040 Version 
//
//---------------------------------------------------------------------------

#include "FastLED.h"
#include "Adafruit_MCP23017.h"
//#include "Hexagon.h"


#define LED_ch0             18     //LED PINS: 0;2;4;5
#define LED_ch1             19     //LED PINS: 0;2;4;5
#define LED_ch2             20     //LED PINS: 0;2;4;5
#define LED_ch3             21     //LED PINS: 0;2;4;5
#define Hexagons_channel_0  12     //Hexagons on CH0
#define Hexagons_channel_1  12     //Hexagons on CH1
#define Hexagons_channel_2  12     //Hexagons on CH2
#define Hexagons_channel_3  14     //Hexagons on CH3
#define Hexagons            Hexagons_channel_0+Hexagons_channel_1+Hexagons_channel_2+Hexagons_channel_3 //Total Hexagons
#define PixelPerHexagon     6      //Pixels on Hexagon PCB
#define NUMPIXELS_ch0       Hexagons_channel_0*PixelPerHexagon
#define NUMPIXELS_ch1       Hexagons_channel_1*PixelPerHexagon
#define NUMPIXELS_ch2       Hexagons_channel_2*PixelPerHexagon
#define NUMPIXELS_ch3       Hexagons_channel_3*PixelPerHexagon
#define NUMPIXELS           NUMPIXELS_ch0+NUMPIXELS_ch1+NUMPIXELS_ch2+NUMPIXELS_ch3   //Total pixel count
#define VOLTS               5
#define MILLIAMPS           2000
#define debug               0       //Activates a point runnning along the LEDS; to check PCB Wiring for LEDS


const byte fadeAmt = 2;

/*
#define NUM_COLORS 8
static const CRGB FieldColors [NUM_COLORS] = 
{
    CRGB::Red,
    CRGB::Blue,
    CRGB::Purple,
    CRGB::Green,
    CRGB::Yellow,
    CRGB::White,
    CRGB::Orange,
    CRGB::Indigo,
};




*/
Adafruit_MCP23017 mcp1;
Adafruit_MCP23017 mcp2;
Adafruit_MCP23017 mcp3;
Adafruit_MCP23017 mcp4;

const uint8_t mcp1_addr = 0; // Adresse 0x20 / 0
const uint8_t mcp2_addr = 1; // Adresse 0x21 / 1
const uint8_t mcp3_addr = 2; // Adresse 0x22 / 2
const uint8_t mcp4_addr = 3; // Adresse 0x23 / 3

CRGB leds[NUMPIXELS] = {0};

int touch_ch0[Hexagons_channel_0];
int touch_ch1[Hexagons_channel_1];
int touch_ch2[Hexagons_channel_2];
int touch_ch3[Hexagons_channel_3];
boolean touch[Hexagons] = {LOW};

boolean TouchBtnPState [Hexagons] = {LOW};
unsigned long lastDebounceTime [Hexagons] = {0};    
unsigned long debounceDelay = 200;    

unsigned long lastOffTime [Hexagons] = {0};    
unsigned long OffDelay = 100; 
 
int count [Hexagons] = {0};     




void setup()
{

//Wire.begin();

  Serial.begin(9600);
  
  /*
*/
    //Setting up one array with many strips
    FastLED.addLeds<NEOPIXEL, LED_ch0>(leds, NUMPIXELS_ch0);                                //Start with index 0
    FastLED.addLeds<NEOPIXEL, LED_ch1>(leds, NUMPIXELS_ch0, NUMPIXELS_ch1);                 //change index to number of pixels on ch0
    FastLED.addLeds<NEOPIXEL, LED_ch2>(leds, NUMPIXELS_ch0+NUMPIXELS_ch1, NUMPIXELS_ch2);
    FastLED.addLeds<NEOPIXEL, LED_ch3>(leds, NUMPIXELS_ch0+NUMPIXELS_ch1+NUMPIXELS_ch2, NUMPIXELS_ch3);
    FastLED.setMaxPowerInVoltsAndMilliamps(VOLTS,MILLIAMPS);  //Current protetction
    FastLED.setBrightness(255); //max brightness
      
      //set adress for mcp
      mcp1.begin(mcp1_addr);
      mcp2.begin(mcp2_addr);
      mcp3.begin(mcp3_addr);
      mcp4.begin(mcp4_addr);
      
      //all mcp pins as inputs
     for (int in=0; in<=15; in++){
      mcp1.pinMode(in, INPUT);
      mcp1.pullUp(in, HIGH); 
      mcp2.pinMode(in, INPUT);
      mcp2.pullUp(in, HIGH); 
      mcp3.pinMode(in, INPUT);
      mcp3.pullUp(in, HIGH); 
      mcp4.pinMode(in, INPUT);
      mcp4.pullUp(in, HIGH);
     }
    
}

void loop()
{
  if(debug==0){
     for (int t=0; t<Hexagons_channel_0; t++){
      touch[t]=mcp1.digitalRead(t);
     }
     for (int t=0; t<Hexagons_channel_1; t++){
      touch[t+Hexagons_channel_0]=mcp2.digitalRead(t);
     }
     for (int t=0; t<Hexagons_channel_2; t++){
      touch[t+Hexagons_channel_0+Hexagons_channel_1]=mcp3.digitalRead(t);
     }
    for (int t=0; t<Hexagons_channel_3; t++){
      touch[t+Hexagons_channel_0+Hexagons_channel_1+Hexagons_channel_2]=mcp4.digitalRead(t);
     } 

  for (int i = 0; i < Hexagons; i++) {
    if (touch[i] != TouchBtnPState[i]) {
      if  ((millis() - lastDebounceTime[i]) > debounceDelay) {
        lastDebounceTime[i] = millis();
        TouchBtnPState[i] = touch[i];
      }
    }
  }
       for (int j=0; j<=Hexagons-1; j++){
        if ((TouchBtnPState[j]==HIGH)){
          for (int k=j*PixelPerHexagon; k<j*PixelPerHexagon+PixelPerHexagon; k++) {
          leds[k] = CRGB::White; //White
            //leds[k] = FieldColors[random(0, NUM_COLORS)];

          }
        }
       }

        for (int j=0; j<=Hexagons-1; j++){  
           if (TouchBtnPState[j]==LOW){
            //if  ((millis() - lastOffTime[j]) > OffDelay) {
             for (int l=j*PixelPerHexagon; l<j*PixelPerHexagon+PixelPerHexagon; l++) {
             leds[l] = leds[l].fadeToBlackBy(fadeAmt);
             }
          }
        }
  }
  else{
        
      for(int i = 0; i < NUMPIXELS; i++) {
      leds[i] = CRGB::White;
      FastLED.show();
      leds[i] = CRGB::Black;
      delay(100);
    }
  }      
      FastLED.show();
}

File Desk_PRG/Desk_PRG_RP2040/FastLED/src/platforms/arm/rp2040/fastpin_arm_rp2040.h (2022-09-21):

#ifndef __FASTPIN_ARM_RP2040_H
#define __FASTPIN_ARM_RP2040_H

#include "pico.h"
#include "hardware/gpio.h"
#include "hardware/structs/sio.h"

FASTLED_NAMESPACE_BEGIN

#if defined(FASTLED_FORCE_SOFTWARE_PINS)
#warning "Software pin support forced, pin access will be sloightly slower."
#define NO_HARDWARE_PIN_SUPPORT
#undef HAS_HARDWARE_PIN_SUPPORT

#else

// warning: set and fastset are not thread-safe! use with caution!
template<uint PIN, uint32_t _MASK> class _RP2040PIN {
public:
  typedef volatile uint32_t * port_ptr_t;
  typedef uint32_t port_t;

  inline static void setOutput() { gpio_set_function(PIN, GPIO_FUNC_SIO); sio_hw->gpio_oe_set = _MASK; }
  inline static void setInput() { gpio_set_function(PIN, GPIO_FUNC_SIO); sio_hw->gpio_oe_clr = _MASK; }

  inline static void hi() __attribute__ ((always_inline)) { sio_hw->gpio_set = _MASK; }
  inline static void lo() __attribute__ ((always_inline)) { sio_hw->gpio_clr = _MASK; }
  inline static void set(register port_t val) __attribute__ ((always_inline)) { sio_hw->gpio_out = val; }

  inline static void strobe() __attribute__ ((always_inline)) { toggle(); toggle(); }

  inline static void toggle() __attribute__ ((always_inline)) { sio_hw->gpio_togl = _MASK; }

  inline static void hi(register port_ptr_t port) __attribute__ ((always_inline)) { hi(); }
  inline static void lo(register port_ptr_t port) __attribute__ ((always_inline)) { lo(); }
  inline static void fastset(register port_ptr_t port, register port_t val) __attribute__ ((always_inline)) { *port = val; }

  inline static port_t hival() __attribute__ ((always_inline)) { return sio_hw->gpio_out | _MASK; }
  inline static port_t loval() __attribute__ ((always_inline)) { return sio_hw->gpio_out & ~_MASK; }
  inline static port_ptr_t port() __attribute__ ((always_inline)) { return &sio_hw->gpio_out; }
  inline static port_ptr_t sport() __attribute__ ((always_inline)) { return &sio_hw->gpio_set; }
  inline static port_ptr_t cport() __attribute__ ((always_inline)) { return &sio_hw->gpio_clr; }
  inline static port_t mask() __attribute__ ((always_inline)) { return _MASK; }
};

#define _FL_DEFPIN(PIN) template<> class FastPin<PIN> : public _RP2040PIN<PIN, 1 << PIN> {};

#define MAX_PIN 29
_FL_DEFPIN(0); _FL_DEFPIN(1); _FL_DEFPIN(2); _FL_DEFPIN(3);
_FL_DEFPIN(4); _FL_DEFPIN(5); _FL_DEFPIN(6); _FL_DEFPIN(7);
_FL_DEFPIN(8); _FL_DEFPIN(9); _FL_DEFPIN(10); _FL_DEFPIN(11);
_FL_DEFPIN(12); _FL_DEFPIN(13); _FL_DEFPIN(14); _FL_DEFPIN(15);
_FL_DEFPIN(16); _FL_DEFPIN(17); _FL_DEFPIN(18); _FL_DEFPIN(19);
_FL_DEFPIN(20); _FL_DEFPIN(21); _FL_DEFPIN(22); _FL_DEFPIN(23);
_FL_DEFPIN(24); _FL_DEFPIN(25); _FL_DEFPIN(26); _FL_DEFPIN(27);
_FL_DEFPIN(28); _FL_DEFPIN(29);

#ifdef PICO_DEFAULT_SPI_TX_PIN
#define SPI_DATA PICO_DEFAULT_SPI_TX_PIN
#else
#define SPI_DATA 19
#endif

#ifdef PICO_DEFAULT_SPI_SCK_PIN
#define SPI_CLOCK PICO_DEFAULT_SPI_SCK_PIN
#else
#define SPI_CLOCK 18
#endif

#define HAS_HARDWARE_PIN_SUPPORT

#endif // FASTLED_FORCE_SOFTWARE_PINS


FASTLED_NAMESPACE_END

#endif // __FASTPIN_ARM_RP2040_H

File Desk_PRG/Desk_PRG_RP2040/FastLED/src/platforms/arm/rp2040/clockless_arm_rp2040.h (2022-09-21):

#ifndef __INC_CLOCKLESS_ARM_RP2040
#define __INC_CLOCKLESS_ARM_RP2040

#include "hardware/structs/sio.h"
#include "../common/m0clockless.h"

#if FASTLED_RP2040_CLOCKLESS_PIO
#include "hardware/clocks.h"
#include "hardware/dma.h"
// compiler throws a warning about comparison that is always true
// silence that so users don't see it
#pragma GCC diagnostic push
#pragma GCC diagnostic ignored "-Wtype-limits"
#include "hardware/pio.h"
#pragma GCC diagnostic pop

#include "pio_gen.h"
#endif

/*
 * This clockless implementation uses RP2040's PIO feature to perform
 * non-blocking transfers to LEDs with very little memory overhead.
 * (allocates one buffer of equal size to the data to be sent)
 *
 * The SDK-provided claims system is used so that resources can used without
 * interfering with other code that behaves well and uses claims.
 *
 * Resource usage is 4 instructions of program memory on the first PIO instance
 * with an unclaimed state machine, said unclaimed PIO state machine, and one
 * DMA channel per instance of ClocklessController.
 * Additionally, one interrupt handler for DMA_IRQ_0 (configurable as shared or
 * exclusive via FASTLED_RP2040_CLOCKLESS_IRQ_SHARED) is used regardless of how
 * many instances are created.
 * 
 * The DMA handler is likely the only significant risk in terms of conflicts,
 * and users can adapt other code to use DMA_IRQ_1 and/or adopt shared handlers
 * to avoid this becoming an issue.
 */

FASTLED_NAMESPACE_BEGIN
#define FASTLED_HAS_CLOCKLESS 1

#if FASTLED_RP2040_CLOCKLESS_PIO
static CMinWait<0> *dma_chan_waits[NUM_DMA_CHANNELS] = {0, 0, 0, 0, 0, 0, 0, 0, 0, 0, 0, 0};
static inline void __isr clockless_dma_complete_handler() {
    for (unsigned int i = 0; i < NUM_DMA_CHANNELS; i++) {
        // if dma triggered for this channel and it's been used (has a CMinWait)
        if ((dma_hw->ints0 & (1 << i)) && dma_chan_waits[i]) {
            dma_hw->ints0 = (1 << i); // clear/ack IRQ
            dma_chan_waits[i]->mark(); // mark the wait
            return;
        }
    }
}
static bool clockless_isr_installed = false;
#endif

template <uint8_t DATA_PIN, int T1, int T2, int T3, EOrder RGB_ORDER = RGB, int XTRA0 = 0, bool FLIP = false, int WAIT_TIME = 50>
class ClocklessController : public CPixelLEDController<RGB_ORDER> {
#if FASTLED_RP2040_CLOCKLESS_PIO
    int dma_channel = -1;
    void *dma_buf = nullptr;
    size_t dma_buf_size = 0;

    float pio_clock_multiplier;
    int T1_mult, T2_mult, T3_mult;

    // increase wait time by time taken to send 4 words (to flush PIO TX buffer)
    CMinWait<WAIT_TIME + ( ((T1 + T2 + T3) * 32 * 4) / (CLOCKLESS_FREQUENCY / 1000000) )> mWait;

    // start a DMA transfer to the PIO state machine from addr (transfer count 32 bit words)
    static void do_dma_transfer(int channel, const void *addr, uint count) {
        dma_channel_set_read_addr(channel, addr, false);
        dma_channel_set_trans_count(channel, count, true);
    }

    // writes bits to an in-memory buffer (to DMA from)
    // pico has enough memory to not really care about using a buffer for DMA
    template<int BITS> __attribute__ ((always_inline)) inline static int writeBitsToBuf(int32_t *out_buf, unsigned int bitpos, uint8_t b)  {
        // not really optimised and I haven't checked output assembly, but this should take ~50 cycles worst case
        // (and on average substantially fewer -- LEDs without XTRA0 should never trigger the second half of the function)

        // position of word that takes highest bits (first word used)
        int wordpos_1 = bitpos >> 5; // bitpos / 32;

        // number of bits from the byte that fit into first word
        int bitcnt_1 = 32 - (bitpos & 0b11111); // bitpos % 32;
        // shift required to place byte within the word
        int bitshift_1 = bitcnt_1 - 8;
        // mask for output bits that are taken from input
        // int32_t bitmask_1 = 0xFF << bitshift_1;
        int32_t bitmask_1 = ((1 << BITS) - 1) << (bitshift_1 - (BITS-8));

        out_buf[wordpos_1] = (out_buf[wordpos_1] & ~bitmask_1) | ((b << bitshift_1) & bitmask_1);

        if (bitcnt_1 >= BITS) return BITS; // fast case for entire byte fitting in word

        // number of bits from the byte to place into second word
        int bitcnt_2 = 8 - bitcnt_1;
        // shift required to place byte within the word
        int bitshift_2 = 32 - bitcnt_2;
        // mask for output bits that are taken from input
        // int32_t bitmask_2 = ((1 << bitcnt_2) - 1) << bitshift_2;
        int32_t bitmask_2 = ((1 << (bitcnt_2 + (BITS-8))) - 1) << (bitshift_2 - (BITS-8)); // fixed XTRA0

        out_buf[wordpos_1 + 1] = (out_buf[wordpos_1 + 1] & ~bitmask_2) | ((b << bitshift_2) & bitmask_2);

        return BITS;
    }
#else
    CMinWait<WAIT_TIME> mWait;
#endif
public:
    virtual void init() {
#if FASTLED_RP2040_CLOCKLESS_PIO
        if (dma_channel != -1) return; // maybe init was called twice somehow? not sure if possible
#endif

        // start by configuring pin as output for blocking fallback
        FastPin<DATA_PIN>::setOutput();
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

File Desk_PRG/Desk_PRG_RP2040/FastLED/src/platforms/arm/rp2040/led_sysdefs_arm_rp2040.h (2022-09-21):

#ifndef __INC_LED_SYSDEFS_ARM_RP2040_H
#define __INC_LED_SYSDEFS_ARM_RP2040_H

#include "hardware/sync.h"

#define FASTLED_ARM
#define FASTLED_ARM_M0_PLUS

// TODO: PORT SPI TO HW
//#define FASTLED_SPI_BYTE_ONLY
#define FASTLED_FORCE_SOFTWARE_SPI
// Force FAST_SPI_INTERRUPTS_WRITE_PINS on becuase two cores running
// simultaneously could lead to data races on GPIO.
// This could potentially be optimised by adding a mask to FastPin's set and
// fastset, but for now it's probably safe to call that out of scope.
#ifndef FAST_SPI_INTERRUPTS_WRITE_PINS
#define FAST_SPI_INTERRUPTS_WRITE_PINS 1
#endif

#define FASTLED_NO_PINMAP

typedef volatile uint32_t RoReg;
typedef volatile uint32_t RwReg;

// #define F_CPU clock_get_hz(clk_sys) // can't use runtime function call
// is the boot-time value in another var already for any platforms?
// it doesn't seem to be, so hardcode the sdk default of 125 MHz
#ifndef F_CPU
#ifdef VARIANT_MCK
#define F_CPU VARIANT_MCK
#else
#define F_CPU 125000000
#endif
#endif

#ifndef VARIANT_MCK
#define VARIANT_MCK F_CPU
#endif

// 8MHz for PIO
// #define CLOCKLESS_FREQUENCY 8000000
#define CLOCKLESS_FREQUENCY F_CPU

// Default to allowing interrupts
#ifndef FASTLED_ALLOW_INTERRUPTS
#define FASTLED_ALLOW_INTERRUPTS 1
#endif

// not sure if this is wanted? but it probably is
#if FASTLED_ALLOW_INTERRUPTS == 1
#define FASTLED_ACCURATE_CLOCK
#endif

// Default to no PROGMEM
#ifndef FASTLED_USE_PROGMEM
#define FASTLED_USE_PROGMEM 0
#endif

// Default to non-blocking PIO-based implemnetation
#ifndef FASTLED_RP2040_CLOCKLESS_PIO
#define FASTLED_RP2040_CLOCKLESS_PIO 1
#endif

// Default to shared interrupt handler for clockless DMA
#ifndef FASTLED_RP2040_CLOCKLESS_IRQ_SHARED
#define FASTLED_RP2040_CLOCKLESS_IRQ_SHARED 1
#endif

// SPI pin defs for old SDK ver
#ifndef PICO_DEFAULT_SPI
#define PICO_DEFAULT_SPI 0
#endif
#ifndef PICO_DEFAULT_SPI_SCK_PIN
#define PICO_DEFAULT_SPI_SCK_PIN 18
#endif
#ifndef PICO_DEFAULT_SPI_TX_PIN
#define PICO_DEFAULT_SPI_TX_PIN 19
#endif
#ifndef PICO_DEFAULT_SPI_RX_PIN
#define PICO_DEFAULT_SPI_RX_PIN 16
#endif
#ifndef PICO_DEFAULT_SPI_CSN_PIN
#define PICO_DEFAULT_SPI_CSN_PIN 17
#endif

static uint32_t saved_interrupt_status;
#define cli() (saved_interrupt_status = save_and_disable_interrupts())
#define sei() (restore_interrupts(saved_interrupt_status))

#endif // __INC_LED_SYSDEFS_ARM_RP2040_H

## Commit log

2022-05-10 PCBs and Demo PRG
    Uploaded my pcb files and the demo prg.
    [BOM-HEX_PCB.csv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]
2022-11-27 Update BOM and add Pictures
    [Tisch_BOM.xlsx]
2023-05-21 add jlcpcb
    Re-Upload of the JLCPCB Parts
    Note: you can leave out the capacitors and the connectors in this BOM
    [BOM-HEX_PCB.csv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]

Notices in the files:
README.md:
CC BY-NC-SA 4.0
